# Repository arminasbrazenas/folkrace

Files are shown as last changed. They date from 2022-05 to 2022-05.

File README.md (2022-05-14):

# Folkrace
Folkrace is a robotics competition in which multiple autonomous robots race against each other in a track.
They have to complete as many laps as they can under a given time limit.
The winner is the robot which completes the most laps in the correct direction.
The driving direction is determined by the judges before the competition.

## Rules
- The robot must be autonomous.
- The maximum dimensions of the robot are 15x20 cm.
- The maximum weight of the robot is 1 kg.
- Each lap in the right direction scores 1 point, while each lap in the wrong direction scores -1 point.
- The width of the track varies between 100 and 120 cm.
- The course has a number of obstacles, such as hills, holes, loose material, obstructing walls or poles and uneven surfaces.

## Robots
### sizedoesntmatter
A relative small robot compared to other participants (as the name suggests), which performs quite well.
All of the architectural design work was done using AutoCAD software.
The robot was 3D printed at our JBG Robotics club with Creality's Ender 5 Pro.

For navigation in the track it uses 3 Sharp Distance Sensors from Pololu, which detect in 10 cm - 80 cm range.
All of the calculations are done by the microcontroller - Arduino Nano.
The robot uses skid steering mechanism, in which the car wheels are fixed in the same position.
So in order to turn, the robot changes the motors' speed.

The code for the robot was written in Arduino IDE, using Arduino language, which is nearly identical to C++.
To determine the motor speed, necessary for the robot to stay in the middle of the track, PID algorithm was used.
To easily change the variable values (PID tuning parameters, maximum speed, etc), I created a phone application on MIT App Inventor.
The application connects to the HC-06 Bluetooth module mounted on the robot, which transfers the data.

#### Achievements
- 1st place Robotų Intelektas 2021
- 2nd place Robotex International 2021

#### Gallery
<div style="display: flex">
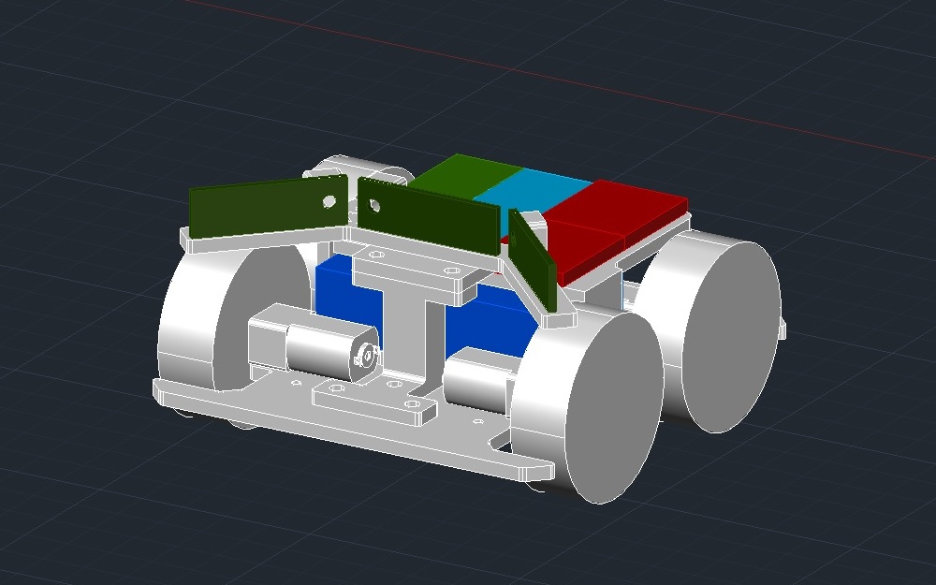
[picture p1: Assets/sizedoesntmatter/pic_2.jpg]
  
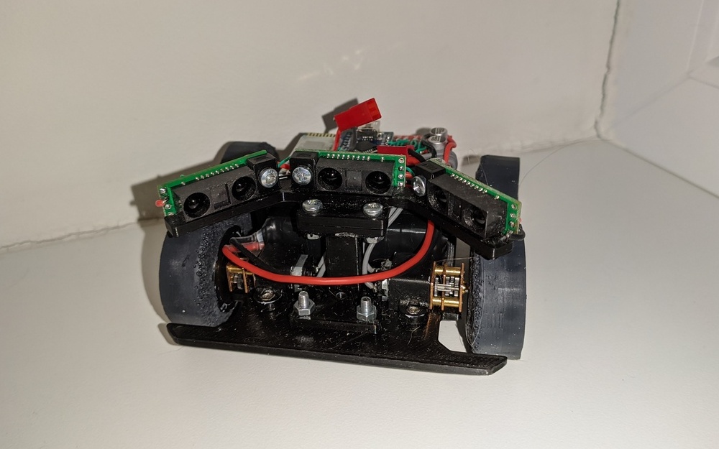
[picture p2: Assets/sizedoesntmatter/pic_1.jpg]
  
</div>

<div style="display: flex">
  
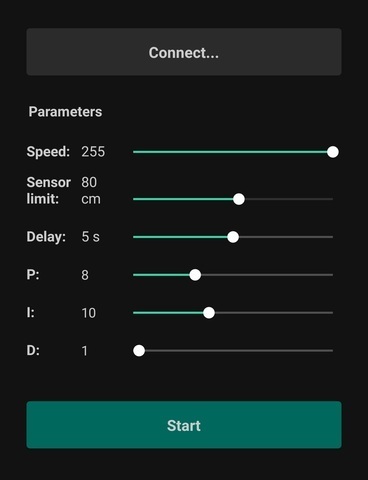
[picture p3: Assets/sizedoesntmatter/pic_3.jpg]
  
</div>

### sizedoesntmatter_v2

A bigger, faster and more complex version of the previous robot.

The robot uses a faster ESP32 microcontroller, which has a built in Bluetooth functionality.
In addition, the distance sensors are exchanged for more accurate ones, which measure the distance of objects up to about 130 cm.
Instead of all wheel drive, this one is powered by 2 more capable Pololu motors in the rear.
Besides, there is a new, more effective steering mechanism.
The steering, which is based on Ackermann's steering geometry, is controlled by a servo motor.

#### Gallery
<div style="display: flex">
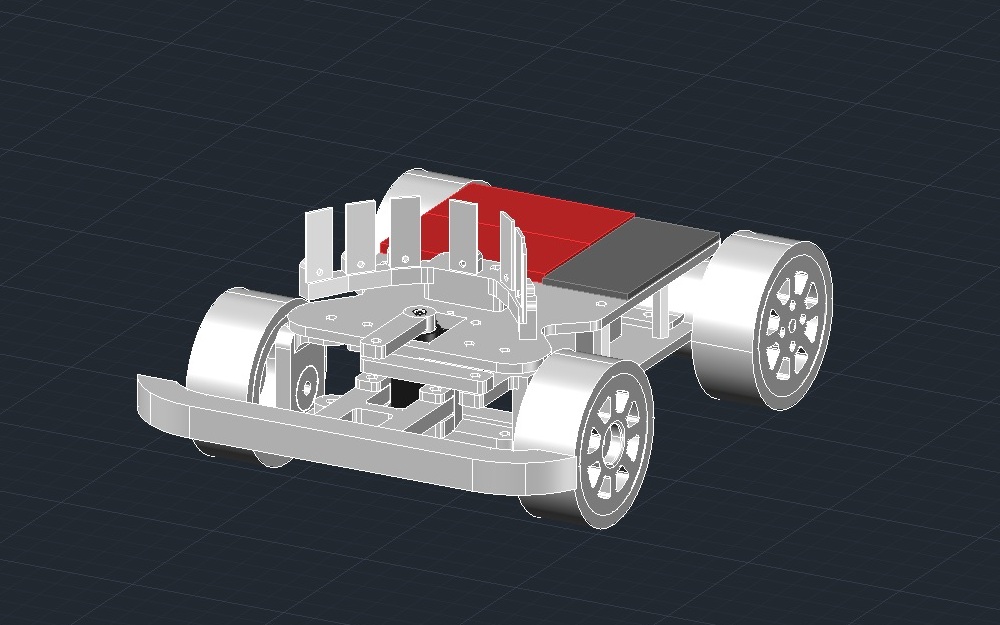
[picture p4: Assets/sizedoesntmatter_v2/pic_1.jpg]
  
</div>

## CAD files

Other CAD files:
CAD/sizedoesntmatter_v2/sizedoesntmatter_v2.dwg
CAD/sizedoesntmatter/sizedoesntmatter.dwg

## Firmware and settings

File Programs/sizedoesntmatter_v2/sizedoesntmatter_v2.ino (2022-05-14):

#include <PID_v1.h>
#include <pidautotuner.h>
#include <BluetoothSerial.h>
#include "Motors.h"
#include "DistanceSensors.h"
#include "ServoSteering.h"
#include "Constants.h"

// Initialize motors
Motor leftMotor(LEFT_MOTOR_FWD_PIN, LEFT_MOTOR_BWD_PIN, LEFT_MOTOR_GPIO_PIN, LEFT_MOTOR_PWM_CHANNEL);
Motor rightMotor(RIGHT_MOTOR_FWD_PIN, RIGHT_MOTOR_BWD_PIN, RIGHT_MOTOR_GPIO_PIN, RIGHT_MOTOR_PWM_CHANNEL);
Motors motors(leftMotor, rightMotor);

// Initialize distance sensors
DistanceSensors distanceSensors(7, (uint8_t[]){ 27, 26, 25, 33, 32, 35, 34 });

// Initialize servo
ServoSteering servo;

// Define variables we'll be connecting steering PID to
double setpoint, input, output;

// Specify steering PID links and initial tuning parameters
double kp = 0.1, ki = 0, kd = 0;
PID steeringPID(&input, &output, &setpoint, kp, ki, kd, REVERSE);

// Initialize bluetooth
BluetoothSerial SerialBT;

String receivedData = "";

void evaluateReceivedData(String& action, float& value) {
  action = "";
  String valueStr = "";
  bool actionFound = false;

  for (int i = 0; i < receivedData.length(); i++) {
    if (!actionFound && !isDigit(receivedData[i])) {
      action += receivedData[i];
    }

    if (isDigit(receivedData[i]) || receivedData[i] == '.') {
      actionFound = true;
      valueStr += receivedData[i];
    }
  }

  value = valueStr.toFloat();
}

void setup() {
  Serial.begin(115200);
  SerialBT.begin("sdm"); // Bluetooth device name
  servo.setup(SERVO_GPIO_PIN);
  motors.setup();
  distanceSensors.setup();
  servo.write(SERVO_POS_MID);

  input = distanceSensors.getDifference();
  setpoint = 0;
  steeringPID.SetOutputLimits(SERVO_POS_MIN, SERVO_POS_MAX);
  steeringPID.SetMode(AUTOMATIC);
}

bool isRobotStarted = false;
int16_t robotSpeed = 0;

unsigned long startMs = 0;
int startDelay = 0;

unsigned long frontObstacleStartMs = 0;
bool obstacleInFront = false;

void loop() {
  while (SerialBT.available()) {
    char receivedChar = SerialBT.read();

    if (receivedChar == '#') {
      String action;
      float value;
      evaluateReceivedData(action, value);

      if (action == "START"){
        isRobotStarted = true;
        startMs = millis();
      } else if (action == "STOP") {
        isRobotStarted = false;
        robotSpeed = 0;
      } else if (action == "SPEED") {
        robotSpeed = (int)value;
      } else if (action == "DELAY") {
        startDelay = (int)value * 1000;
      } else if (action == "P") {
        kp = value;
      } else if (action == "I") {
        ki = value;
      } else if (action == "D") {
        kd = value;
      }

      if (action == "P" || action == "I" || action == "D") {
        // Reset PID
        steeringPID.SetTunings(kp, ki, kd);
        steeringPID.SetOutputLimits(0.0, 1.0);  // Forces minimum up to 0.0
        steeringPID.SetOutputLimits(-1.0, 0.0);  // Forces maximum down to 0.0
        steeringPID.SetOutputLimits(SERVO_POS_MIN, SERVO_POS_MAX);  // Set the limits back to normal
      }

      receivedData = "";
    } else {
      receivedData += receivedChar;
    }
  }

  if (isRobotStarted && startMs + startDelay <= millis()) {
    motors.left.drive(robotSpeed);
    motors.right.drive(robotSpeed);
    input = distanceSensors.getDifference();
    steeringPID.Compute();

    servo.write(output);

    
    // If middle sensor detects an obstacle in front
    if (distanceSensors.sensors[3].getDistance() <= 150) {
      // If obstacle in front is detected for the first time
      if (!obstacleInFront) {
        frontObstacleStartMs = millis();
        obstacleInFront = true;
      }

      // If obstacle in front has been there for a certain amount of time, go back
      if (obstacleInFront && millis() - frontObstacleStartMs >= 1000) {
        servo.write(SERVO_POS_MID);
        motors.left.drive(-100);
        motors.right.drive(-100);
        delay(800);

        obstacleInFront = false;
        frontObstacleStartMs = 0;
      } else {
        obstacleInFront = false;
        frontObstacleStartMs = 0;
      }
    }
  } else {
    motors.left.drive(0);
    motors.right.drive(0);
    servo.write(SERVO_POS_MID);
  }
}

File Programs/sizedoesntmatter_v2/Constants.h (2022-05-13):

#ifndef CONSTANTS_H
#define CONSTANTS_H

#include "Arduino.h"

const uint8_t MOTOR_PWM_RESOLUTION = 8;
const uint16_t MOTOR_PWM_FREQUENCY = 30000;

const uint8_t LEFT_MOTOR_FWD_PIN = 21;
const uint8_t LEFT_MOTOR_BWD_PIN = 22;
const uint8_t LEFT_MOTOR_GPIO_PIN = 23;
const uint8_t LEFT_MOTOR_PWM_CHANNEL = 5;

const uint8_t RIGHT_MOTOR_FWD_PIN = 5;
const uint8_t RIGHT_MOTOR_BWD_PIN = 19;
const uint8_t RIGHT_MOTOR_GPIO_PIN = 18;
const uint8_t RIGHT_MOTOR_PWM_CHANNEL = 6;

const uint8_t SERVO_GPIO_PIN = 12;
const uint8_t SERVO_POS_MIN = 50;
const uint8_t SERVO_POS_MID = 85;
const uint8_t SERVO_POS_MAX = 120;

#endif

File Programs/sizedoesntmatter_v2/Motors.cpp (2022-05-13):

#include "Motors.h"

Motor::Pins::Pins(const uint8_t _fwd, const uint8_t _bwd, const uint8_t _gpio)
  : fwd(_fwd), bwd(_bwd), gpio(_gpio) {};

Motor::Pwm::Pwm(const uint8_t _channel)
  : channel(_channel) {};

Motor::Motor(const uint8_t fwd, const uint8_t bwd, const uint8_t gpio, const uint8_t ch)
  : pins(fwd, bwd, gpio), pwm(ch) {};

void Motor::setup() {
  pinMode(this->pins.fwd, OUTPUT);
  pinMode(this->pins.bwd, OUTPUT);
  ledcAttachPin(this->pins.gpio, this->pwm.channel);
  ledcSetup(this->pwm.channel, this->pwm.frequency, this->pwm.resolution);
}

void Motor::drive(int16_t velocity) {  
  if (velocity > 0) {
    digitalWrite(this->pins.fwd, HIGH);
    digitalWrite(this->pins.bwd, LOW);
  } else  if (velocity < 0){
    digitalWrite(this->pins.fwd, LOW);
    digitalWrite(this->pins.bwd, HIGH);
  } else {
    digitalWrite(this->pins.fwd, LOW);
    digitalWrite(this->pins.bwd, LOW);
  }

  ledcWrite(this->pwm.channel, abs(velocity));
};

Motors::Motors(Motor& _left, Motor& _right)
  : left(_left), right(_right) {};

void Motors::setup() {
  this->left.setup();
  this->right.setup();
}
